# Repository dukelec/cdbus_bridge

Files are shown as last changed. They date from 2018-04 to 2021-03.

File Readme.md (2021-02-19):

## CDBUS Bridge

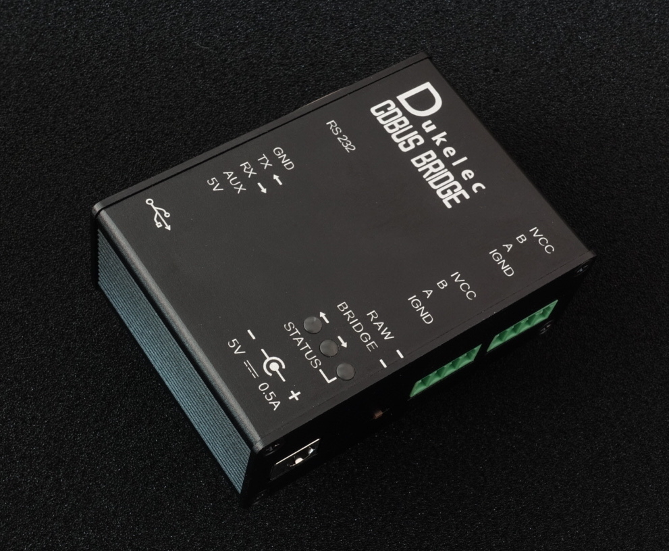
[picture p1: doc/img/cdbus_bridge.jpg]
cdbus_bridge

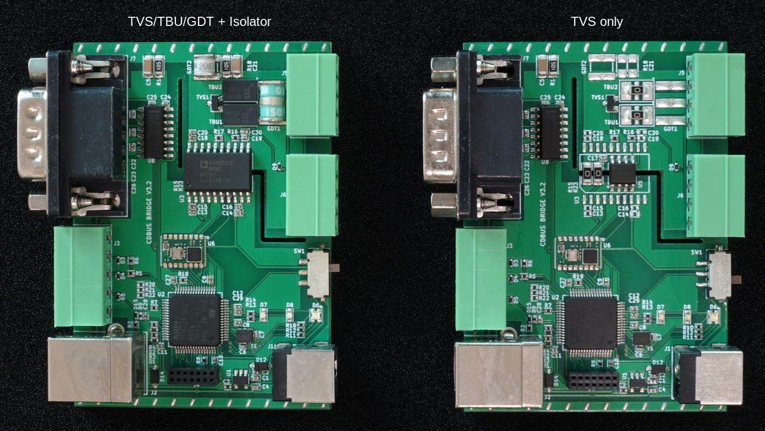
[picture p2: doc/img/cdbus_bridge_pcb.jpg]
cdbus_bridge_pcb


CDBUS Bridge has two types of communication ports, which are 3 serial ports and 2 RS485 ports:
 - Only one of the three serial ports will be in use at the same time. Inserting USB will switch over to the configuration-free USB serial port (the communication rate will not be affected by the selected baud rate);
 - The two RS485 ports are internally connected for easy wiring (or pull up, pull down, and termination resistors).

CDBUS Bridge has two modes (requires different firmware to be programmed, default is Bridge mode):

### Bridge Mode (Serial to RS485)

Switch Definition Changed: Forcing 115200 baud rate if the switch is in RAW when powering up.

bridge_mode

### Raw Mode (Serial passthrough)

raw_mode

## GUI Configuration

CDBUS GUI Tool: https://github.com/dukelec/cdbus_gui

When configuring the Bridge as the target, do not select the CDBUS Bridge selection box, set the local MAC to 0xaa and the target address to 80:00:55.

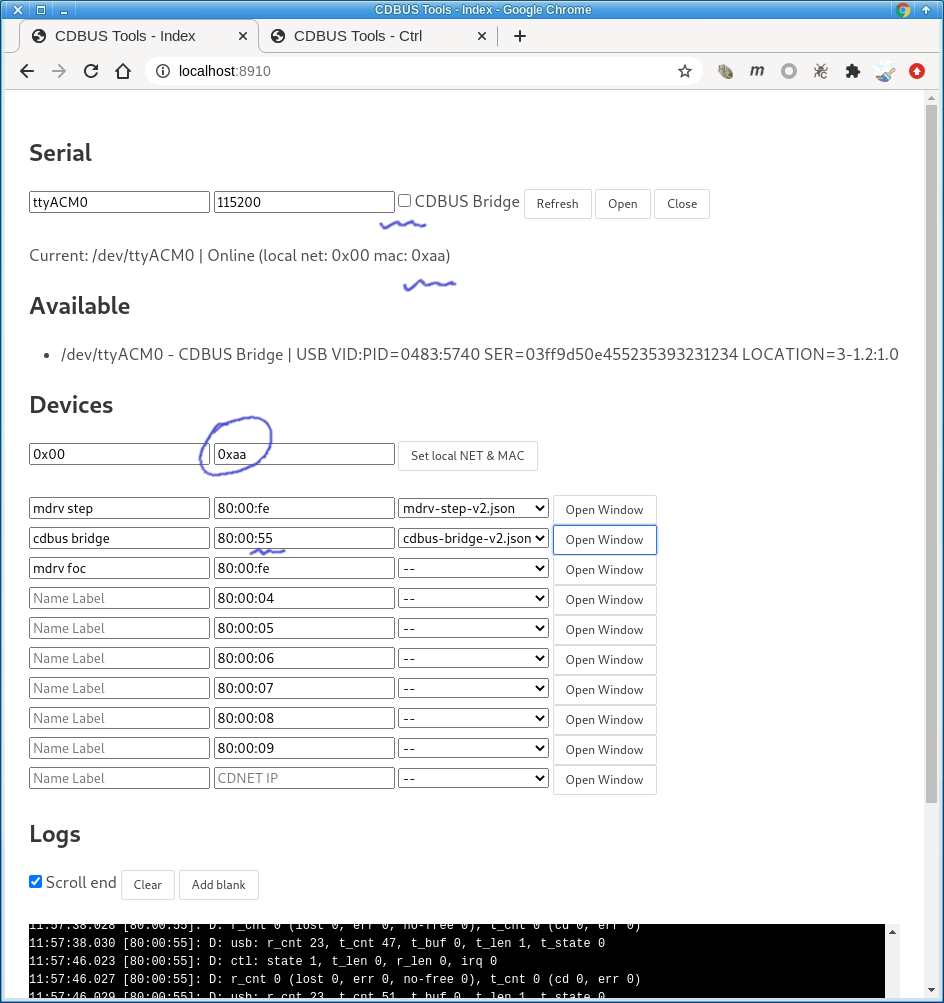
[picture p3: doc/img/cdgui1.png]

<br><br>

After modifying the configuration, write 1 to save_conf to save the configuration to flash.

If you need to restore the default configuration, change magic_code to another value and save it to flash. Then reapply power.

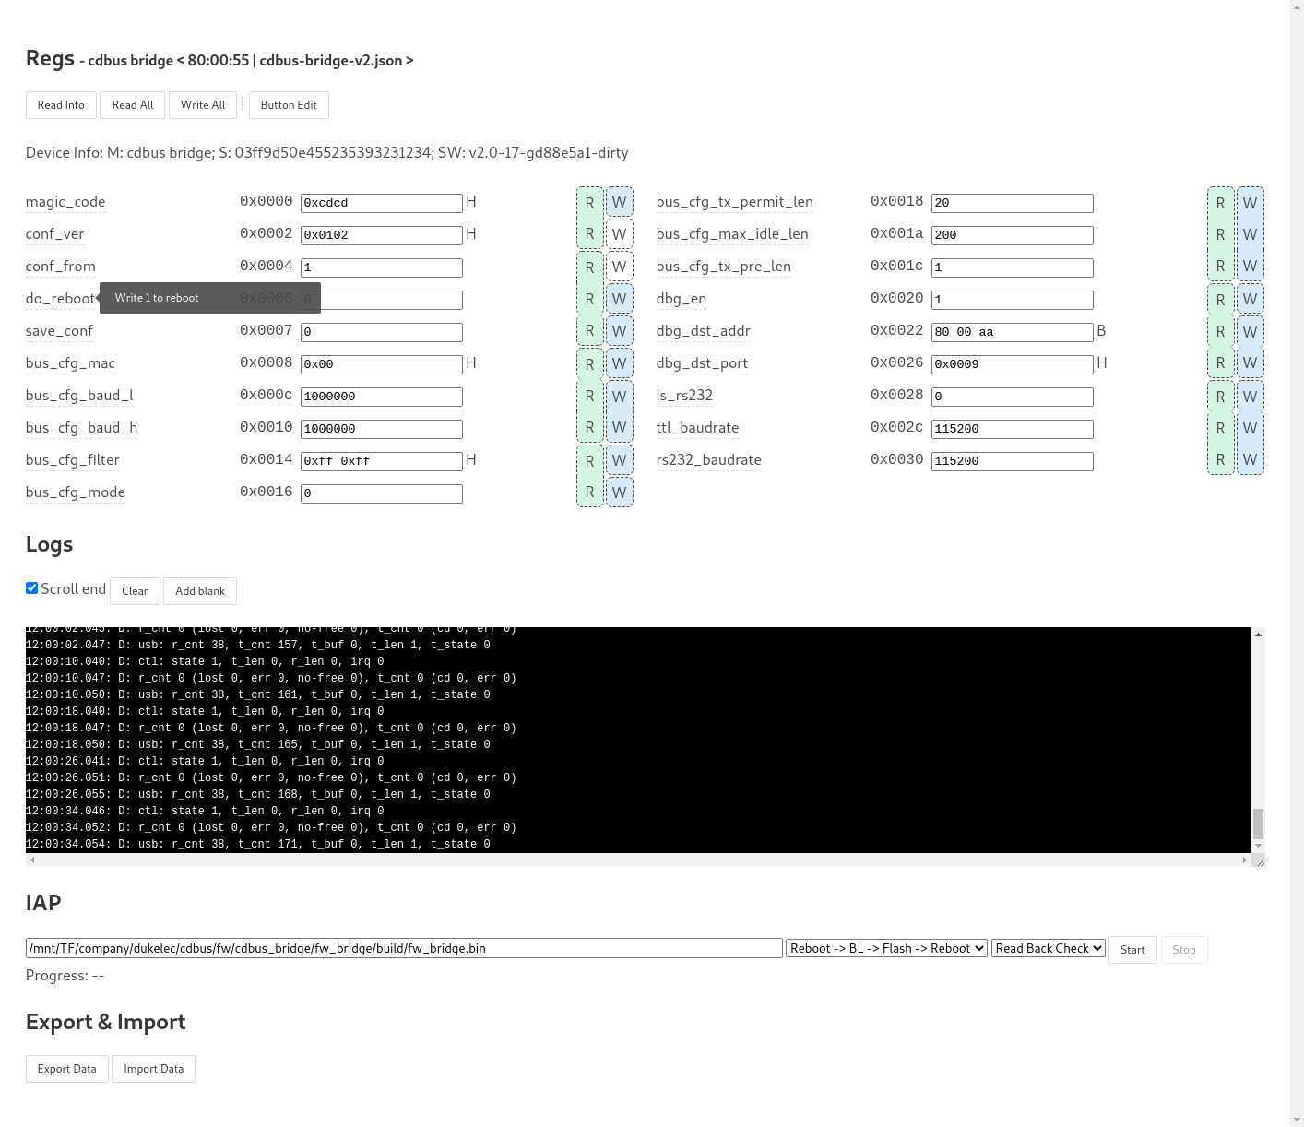
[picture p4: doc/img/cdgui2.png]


## Download Source Code

```
git clone --recurse-submodules https://github.com/dukelec/cdbus_bridge.git
```

## Test

### Prepare
 - Linux: pip3 install pythoncrc pyserial
 - Mac: pip3 install readline pythoncrc pyserial
 - Windows: pip3 install pyreadline pythoncrc pyserial

Please refer scripts' `--help` message and the `Readme.md` under `sw/` folder, e.g.:

```
cd sw/cdbus_tools/
./cdbus_terminal.py --help
```

Note: The default is 3 seconds for bootloader mode on power-on. The status light will flash when it jumps to the main program. Please use the relevant script tool (except IAP) after this.

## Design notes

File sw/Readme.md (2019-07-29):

### Read config from device
```
cdbus_tools/cdbus_iap.py --direct --addr=0x0801f800 --size=36 --out-file conf.bin
```

### Convert to cfg
```
./config_conv.py --to-cfg --bin conf.bin --cfg conf.cfg
```

#### Or creat cfg by default config
```
./config_conv.py --to-cfg --cfg conf.cfg
```

### Convert cfg back to bin
```
./config_conv.py --to-bin --cfg conf.cfg --bin conf.bin
```

### Write back to device
```
cdbus_tools/cdbus_iap.py --direct --addr=0x0801f800 --in-file conf.bin
```

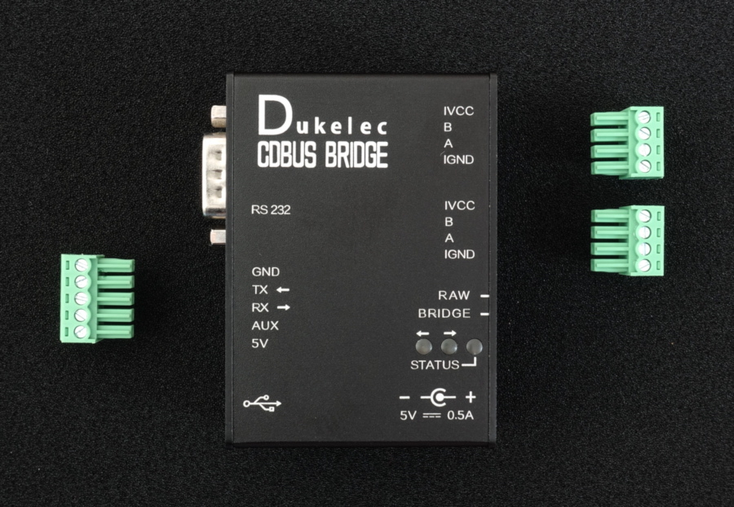
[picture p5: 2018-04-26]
doc/img/cdbus_bridge_top.jpg

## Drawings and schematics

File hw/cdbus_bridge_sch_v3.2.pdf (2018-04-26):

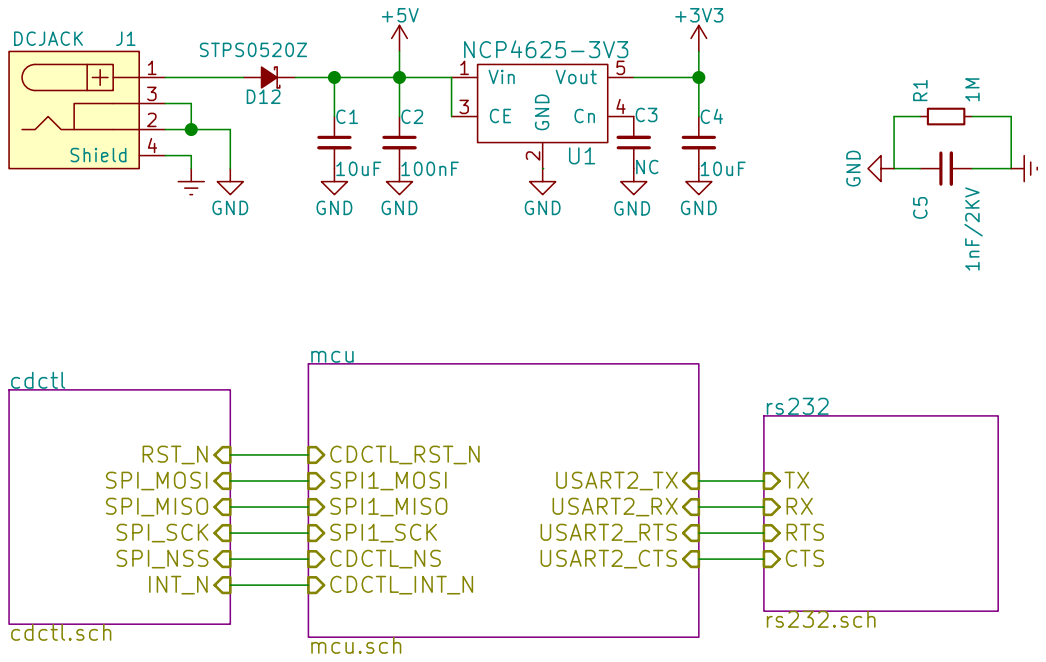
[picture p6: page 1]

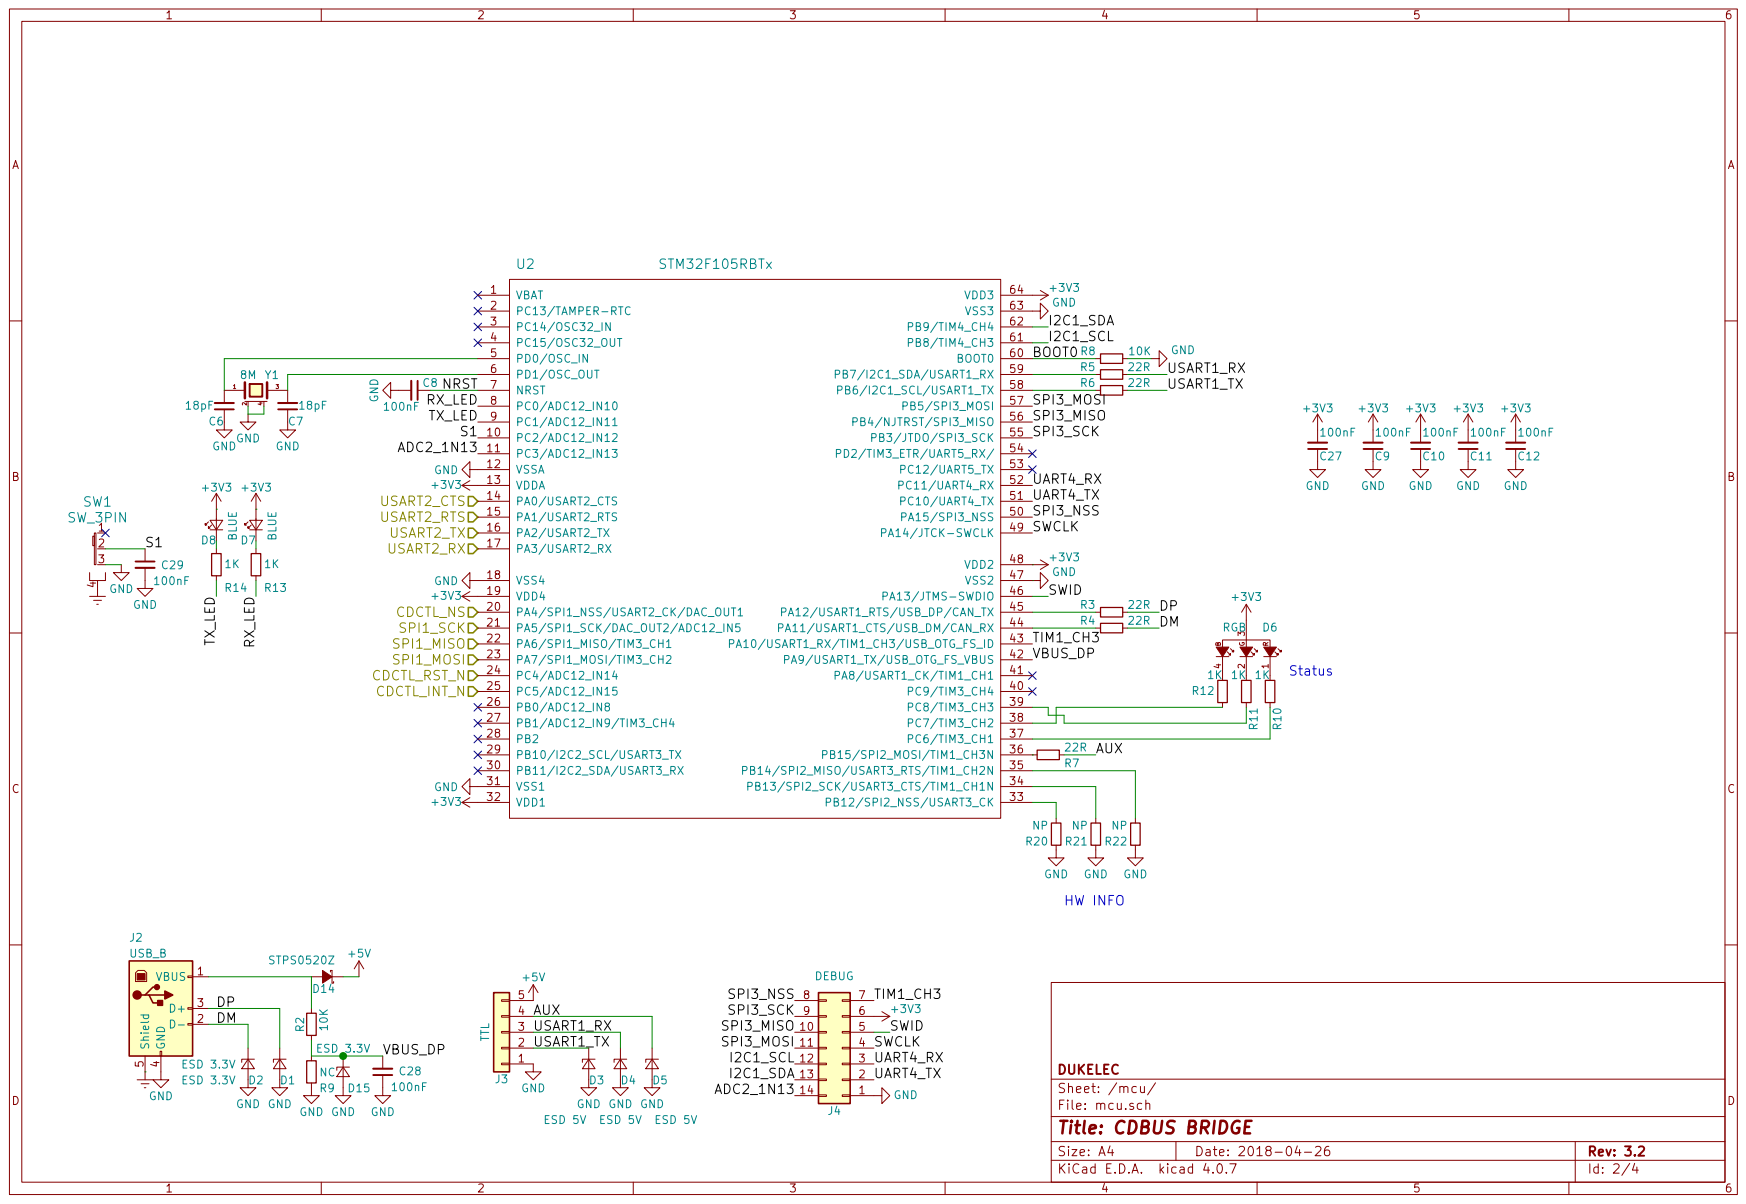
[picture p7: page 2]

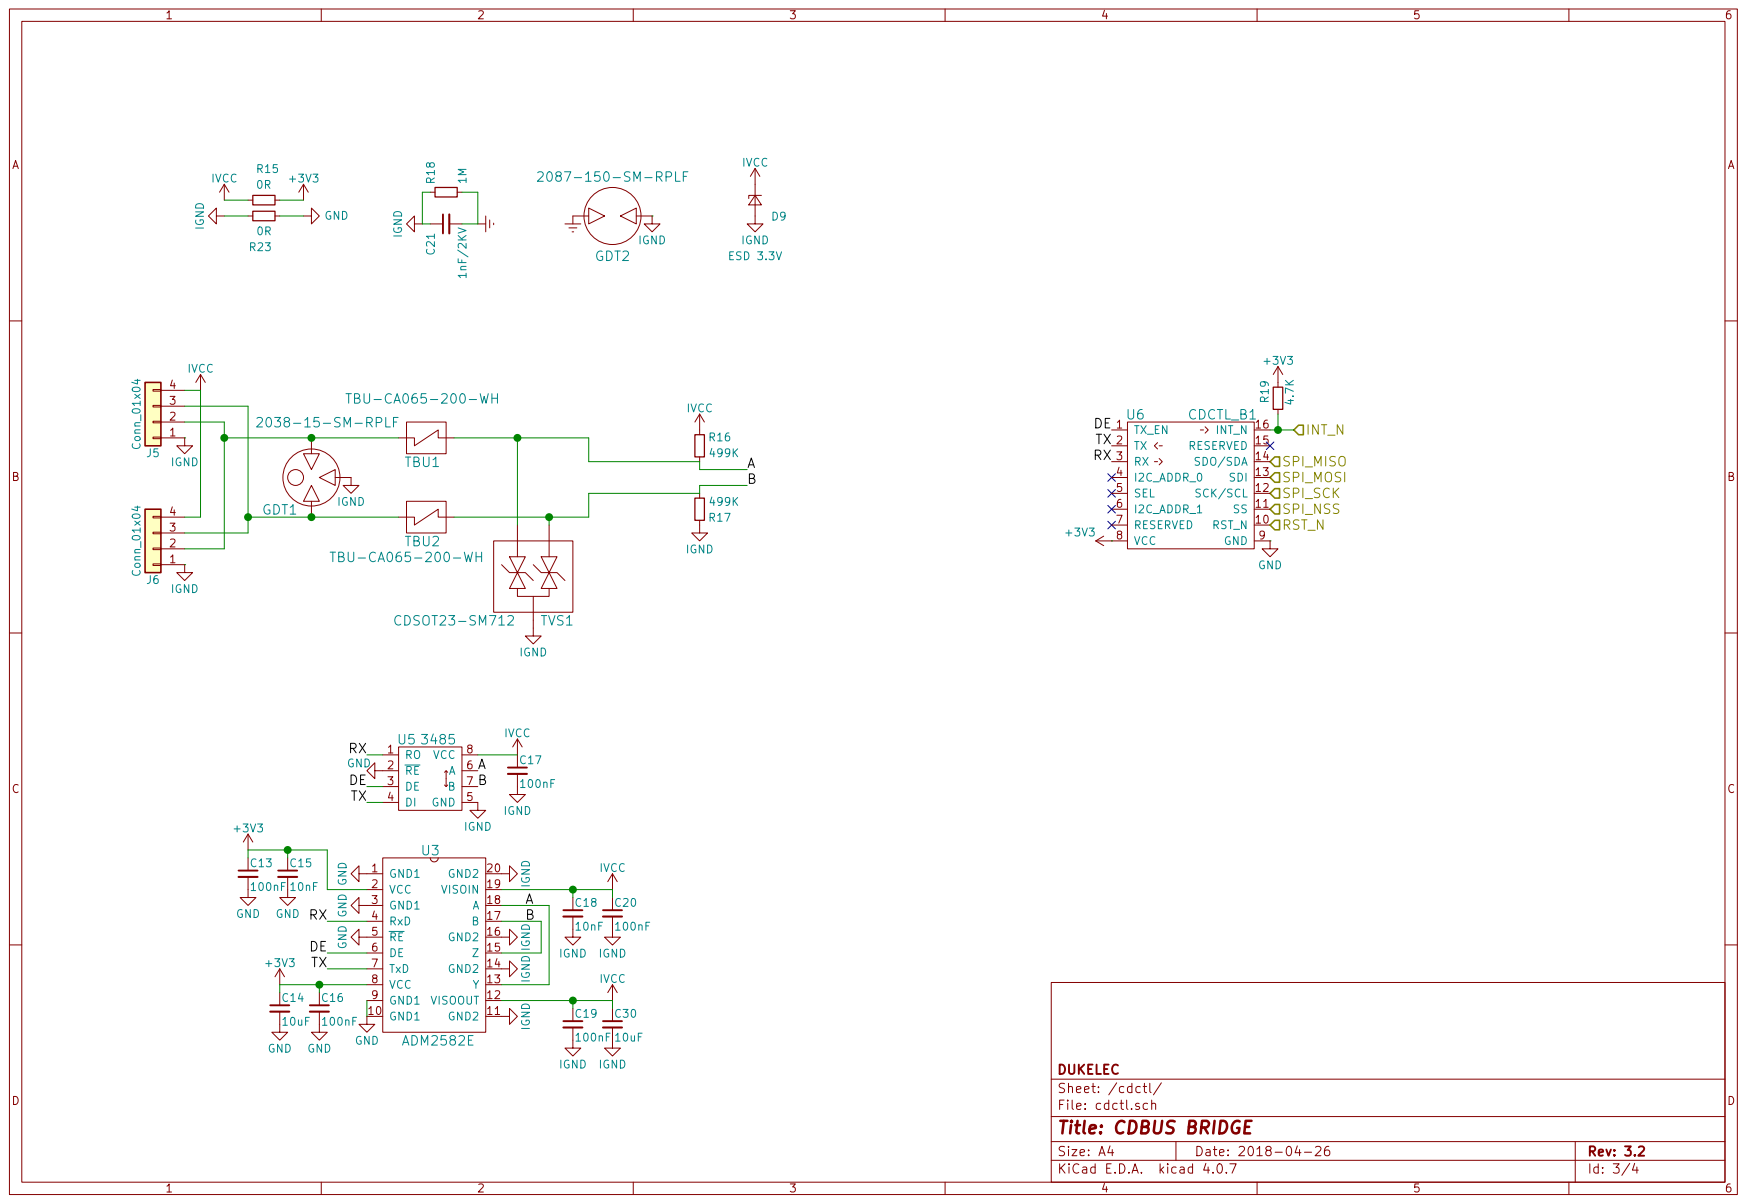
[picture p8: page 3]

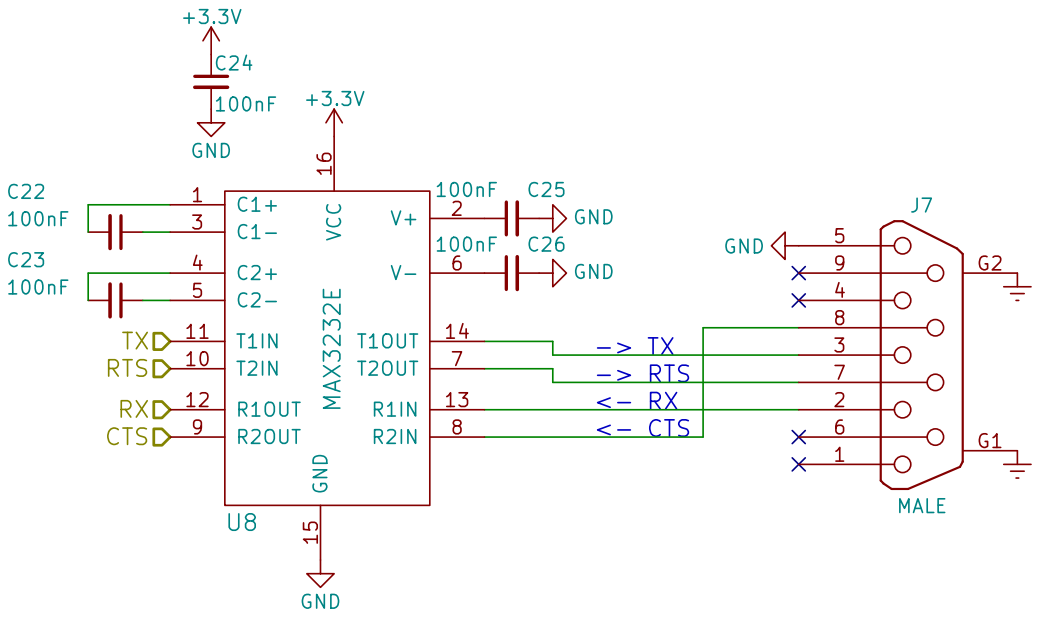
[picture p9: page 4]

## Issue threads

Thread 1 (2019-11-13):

请教，该项目里的 list 是线程安全的吗？

NikolaDi, 2019-11-13:
我想在linux 多线程环境中使用，是不是还要自己添加互斥锁？

NikolaDi, 2019-11-13:
是不是只要在 list_head_t 里加一个 pthread_mutex_t 就行了吧

dukelec, 2019-11-13:
我的這個版本不是線程安全的。
可以你那樣改，也可以考慮把鎖加在上一層用結構體中。
另外，linux kernel 中的 list 大多都是免鎖，你也可以瞭解一下。

NikolaDi, 2019-11-14:
thanks

Closed 2019-11-14.

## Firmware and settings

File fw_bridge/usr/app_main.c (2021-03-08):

/*
 * Software License Agreement (MIT License)
 *
 * Copyright (c) 2017, DUKELEC, Inc.
 * All rights reserved.
 *
 * Author: Duke Fong <duke@dukelec.com>
 */

#include "app_main.h"

extern ADC_HandleTypeDef hadc1;
extern UART_HandleTypeDef huart1;
extern UART_HandleTypeDef huart2;
extern UART_HandleTypeDef huart4;
extern SPI_HandleTypeDef hspi1;
extern USBD_HandleTypeDef hUsbDeviceFS;

static  gpio_t led_r = { .group = LED_R_GPIO_Port, .num = LED_R_Pin };
static  gpio_t led_g = { .group = LED_G_GPIO_Port, .num = LED_G_Pin };
static  gpio_t led_b = { .group = LED_B_GPIO_Port, .num = LED_B_Pin };
static  gpio_t led_tx = { .group = LED_TX_GPIO_Port, .num = LED_TX_Pin };
static  gpio_t led_rx = { .group = LED_RX_GPIO_Port, .num = LED_RX_Pin };
static  gpio_t sw = { .group = SW_MODE_GPIO_Port, .num = SW_MODE_Pin };

uart_t debug_uart = { .huart = &huart4 };
static uart_t ttl_uart = { .huart = &huart1 };
static uart_t rs232_uart = { .huart = &huart2 };
uart_t *hw_uart = NULL;

static gpio_t r_rst_n = { .group = CDCTL_RST_N_GPIO_Port, .num = CDCTL_RST_N_Pin };
static gpio_t r_int_n = { .group = CDCTL_INT_N_GPIO_Port, .num = CDCTL_INT_N_Pin };
static gpio_t r_ns = { .group = CDCTL_NS_GPIO_Port, .num = CDCTL_NS_Pin };
static spi_t r_spi = { .hspi = &hspi1, .ns_pin = &r_ns };

#define CDC_RX_MAX 6
#define CDC_TX_MAX 6
static cdc_buf_t cdc_rx_alloc[CDC_RX_MAX];
static cdc_buf_t cdc_tx_alloc[CDC_TX_MAX];
list_head_t cdc_rx_free_head = {0};
list_head_t cdc_tx_free_head = {0};
list_head_t cdc_rx_head = {0};
list_head_t cdc_tx_head = {0};
cdc_buf_t *cdc_rx_buf = NULL;
cdc_buf_t *cdc_tx_buf = NULL;

static cd_frame_t frame_alloc[FRAME_MAX];
list_head_t frame_free_head = {0};

static cdn_pkt_t packet_alloc[PACKET_MAX];

static cdctl_dev_t r_dev = {0};    // 485
cduart_dev_t d_dev = {0};   // uart / usb
cdn_ns_t dft_ns = {0};      // CDNET

int usb_rx_cnt = 0;
int usb_tx_cnt = 0;
static bool cdc_need_flush = false;

uint8_t circ_buf[CIRC_BUF_SZ];
uint32_t rd_pos = 0;

static int test_err = 0;
static int last_err = 0;
static uint32_t local_cnt = 0;
static uint32_t remote_cnt = 0;
static uint32_t cmd_in_cnt = 0;


static void device_init(void)
{
    int i;
    cdn_init_ns(&dft_ns);

    for (i = 0; i < CDC_RX_MAX; i++)
        list_put(&cdc_rx_free_head, &cdc_rx_alloc[i].node);
    for (i = 0; i < CDC_TX_MAX; i++)
        list_put(&cdc_tx_free_head, &cdc_tx_alloc[i].node);
    for (i = 0; i < FRAME_MAX; i++)
        list_put(&frame_free_head, &frame_alloc[i].node);
    for (i = 0; i < PACKET_MAX; i++)
        list_put(&dft_ns.free_pkts, &packet_alloc[i].node);

    cdc_rx_buf = list_get_entry(&cdc_rx_free_head, cdc_buf_t);

    if (gpio_get_value(&sw)) {
        csa.bus_cfg.baud_l = 115200;
        csa.bus_cfg.baud_h = 115200;
    }
    cdctl_dev_init(&r_dev, &frame_free_head, &csa.bus_cfg, &r_spi, &r_rst_n, &r_int_n);

    cduart_dev_init(&d_dev, &frame_free_head);
    d_dev.remote_filter[0] = 0xaa;
    d_dev.remote_filter_len = 1;
    d_dev.local_filter[0] = 0x55;
    d_dev.local_filter[1] = 0x56;
    d_dev.local_filter_len = 2;
    
    //                    uart / usb
    cdn_add_intf(&dft_ns, &d_dev.cd_dev, 0, 0x55);

    if (!csa.is_rs232) {
        hw_uart = &ttl_uart;
    } else {
        hw_uart = &rs232_uart;
    }
}

void set_led_state(led_state_t state)
{
    static bool is_err = false;
    if (is_err)
        return;

    switch (state) {
    case LED_POWERON:
        gpio_set_value(&led_r, 1);
        gpio_set_value(&led_g, 1);
        gpio_set_value(&led_b, 0);
        break;
    case LED_WARN:
        gpio_set_value(&led_r, 0);
        gpio_set_value(&led_g, 0);
        gpio_set_value(&led_b, 1);
        break;
    default:
    case LED_ERROR:
        is_err = true;
        gpio_set_value(&led_r, 0);
        gpio_set_value(&led_g, 1);
        gpio_set_value(&led_b, 1);
        break;
    }
}

static void data_led_task(void)
{
    static uint32_t tx_t_last = 0;
    static uint32_t rx_t_last = 0;
    static uint32_t tx_cnt_last = 0;
    static uint32_t rx_cnt_last = 0;

    if (rx_cnt_last != cmd_in_cnt) {
        rx_cnt_last = cmd_in_cnt;
        rx_t_last = get_systick();
        gpio_set_value(&led_rx, 0);
    }
    if (tx_cnt_last != local_cnt) {
        tx_cnt_last = local_cnt;
        tx_t_last = get_systick();
        gpio_set_value(&led_tx, 0);
    }
    /*
    if (rx_cnt_last != r_dev.rx_cnt) {
        rx_cnt_last = r_dev.rx_cnt;
        rx_t_last = get_systick();
        gpio_set_value(&led_rx, 0);
    }
    if (tx_cnt_last != r_dev.tx_cnt) {
        tx_cnt_last = r_dev.tx_cnt;
        tx_t_last = get_systick();
        gpio_set_value(&led_tx, 0);
    }
    */

    if (gpio_get_value(&led_rx) == 0 && get_systick() - rx_t_last > 10)
        gpio_set_value(&led_rx, 1);
    if (gpio_get_value(&led_tx) == 0 && get_systick() - tx_t_last > 10)
        gpio_set_value(&led_tx, 1);
}


extern uint32_t end; // end of bss
#define STACK_CHECK_SKIP 0x200
#define STACK_CHECK_SIZE (64 + STACK_CHECK_SKIP)

static void stack_check_init(void)
{
    int i;
    printf("stack_check_init: skip: %p ~ %p, to %p\n",
            &end, &end + STACK_CHECK_SKIP, &end + STACK_CHECK_SIZE);
    for (i = STACK_CHECK_SKIP; i < STACK_CHECK_SIZE; i+=4)
        *(uint32_t *)(&end + i) = 0xababcdcd;
}

static void stack_check(void)
{
    int i;
    for (i = STACK_CHECK_SKIP; i < STACK_CHECK_SIZE; i+=4) {
        if (*(uint32_t *)(&end + i) != 0xababcdcd) {
            printf("stack overflow %p (skip: %p ~ %p): %08lx\n",
                    &end + i, &end, &end + STACK_CHECK_SKIP, *(uint32_t *)(&end + i));
            while (true);
        }
    }
}


static void dump_hw_status(void)
{
    static int t_l = 0;
    if (get_systick() - t_l > 8000) {
        //USBD_CDC_HandleTypeDef *hcdc = (USBD_CDC_HandleTypeDef*)hUsbDeviceFS.pClassData;
        t_l = get_systick();

        d_debug("ctl: state %d, t_len %d, r_len %d, irq %d\n",
                r_dev.state, r_dev.tx_head.len, r_dev.rx_head.len,
                !gpio_get_value(r_dev.int_n));
        d_debug("  r_cnt %d (lost %d, err %d, no-free %d), t_cnt %d (cd %d, err %d)\n",
                r_dev.rx_cnt, r_dev.rx_lost_cnt, r_dev.rx_error_cnt,
                r_dev.rx_no_free_node_cnt,
                r_dev.tx_cnt, r_dev.tx_cd_cnt, r_dev.tx_error_cnt);
        //d_debug("usb: r_cnt %d, t_cnt %d, t_buf %p, t_len %d, t_state %x\n",
        //        usb_rx_cnt, usb_tx_cnt, cdc_tx_buf, cdc_tx_head.len, hcdc->TxState);
        d_info("TTT: local_cnt %d, remote_cnt %d\n", local_cnt, remote_cnt);
        if (test_err || last_err)
            d_error("test: err_cnt %d, last: %d !!!!!!!!\n", test_err, last_err);
    }
}


void cdbus_test(void)
{
    static uint32_t size = 0;
    uint8_t target_mac;

    cd_dev_t *cd_dev = &r_dev.cd_dev;
    target_mac = ~csa.bus_cfg.mac; // avoid addr 0, or specify an address

    if (gpio_get_value(&sw)) {
        cd_frame_t *frame = cd_dev->get_free_frame(cd_dev);
        if (frame) {
            frame->dat[0] = csa.bus_cfg.mac;
            frame->dat[1] = target_mac;
            frame->dat[2] = size; // frame size
            *(uint32_t *)&frame->dat[4] = local_cnt++;
            cd_dev->put_tx_frame(cd_dev, frame);

            if (++size > 253)
                size = 0;
        }
    }
}


void app_main(void)
{
    printf("\nstart app_main (bridge)...\n");
    stack_check_init();
    debug_init(&dft_ns, &csa.dbg_dst, &csa.dbg_en);
    load_conf();
    device_init();
    common_service_init();
    printf("conf: %s\n", csa.conf_from ? "load from flash" : "use default");
    d_info("conf: %s\n", csa.conf_from ? "load from flash" : "use default");
    set_led_state(LED_POWERON);
    app_bridge_init();
    HAL_UART_Receive_DMA(hw_uart->huart, circ_buf, CIRC_BUF_SZ);
    csa_list_show();

    while (true) {
        USBD_CDC_HandleTypeDef *hcdc = (USBD_CDC_HandleTypeDef*)hUsbDeviceFS.pClassData;

        if (!csa.usb_online && hUsbDeviceFS.dev_state == USBD_STATE_CONFIGURED) {
            printf("usb connected\n");
            csa.usb_online = true;
            HAL_UART_DMAStop(hw_uart->huart);
        }

        if (cdc_tx_buf) {
            if (csa.usb_online) {
                if (hcdc->TxState == 0) {
                    list_put(&cdc_tx_free_head, &cdc_tx_buf->node);
                    cdc_tx_buf = NULL;
                }
            } else { // hw_uart
                if (hw_uart->huart->TxXferCount == 0) {
                    hw_uart->huart->gState = HAL_UART_STATE_READY;
                    list_put(&cdc_tx_free_head, &cdc_tx_buf->node);
                    cdc_tx_buf = NULL;
                    //d_verbose("hw_uart dma done.\n");
                }
            }
        }
        if (cdc_tx_head.first) {
            if (!cdc_tx_buf && hcdc->TxState == 0) {
                cdc_buf_t *bf = list_entry(cdc_tx_head.first, cdc_buf_t);
                if (bf->len != 0) {
                    if (csa.usb_online) {
                        local_irq_disable();
                        CDC_Transmit_FS(bf->dat, bf->len);
                        local_irq_enable();
                        cdc_need_flush = true;
                    } else { // hw_uart
                        //d_verbose("hw_uart dma tx...\n");
                        HAL_UART_Transmit_DMA(hw_uart->huart, bf->dat, bf->len);
                    }
                    list_get(&cdc_tx_head);
                    cdc_tx_buf = bf;

                } else if (cdc_need_flush) {
                    local_irq_disable();
                    CDC_Transmit_FS(NULL, 0);
                    local_irq_enable();
                    cdc_need_flush = false;
                }
            }
        }

        data_led_task();
        stack_check();
        cdbus_test();
        dump_hw_status();
        cdn_routine(&dft_ns); // handle cdnet
        common_service_routine();
        app_bridge();
        debug_flush(false);
    }
}


void HAL_GPIO_EXTI_Callback(uint16_t GPIO_Pin)
{
    if (GPIO_Pin == r_int_n.num) {
        cdctl_int_isr(&r_dev);
    }
}

void HAL_SPI_TxRxCpltCallback(SPI_HandleTypeDef *hspi)
{
    cdctl_spi_isr(&r_dev);
}
void HAL_SPI_RxCpltCallback(SPI_HandleTypeDef *hspi)
{
    cdctl_spi_isr(&r_dev);
}
void HAL_SPI_TxCpltCallback(SPI_HandleTypeDef *hspi)
{
    cdctl_spi_isr(&r_dev);
}
void HAL_SPI_ErrorCallback(SPI_HandleTypeDef *hspi)
{
    d_error("spi error...\n");
}

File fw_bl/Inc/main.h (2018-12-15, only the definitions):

#define LED_RX_Pin GPIO_PIN_0
#define LED_RX_GPIO_Port GPIOC
#define LED_TX_Pin GPIO_PIN_1
#define LED_TX_GPIO_Port GPIOC
#define SW_MODE_Pin GPIO_PIN_2
#define SW_MODE_GPIO_Port GPIOC
#define CDCTL_NS_Pin GPIO_PIN_4
#define CDCTL_NS_GPIO_Port GPIOA
#define CDCTL_RST_N_Pin GPIO_PIN_4
#define CDCTL_RST_N_GPIO_Port GPIOC
#define CDCTL_INT_N_Pin GPIO_PIN_5
#define CDCTL_INT_N_GPIO_Port GPIOC
#define CDCTL_INT_N_EXTI_IRQn EXTI9_5_IRQn
#define LED_R_Pin GPIO_PIN_6
#define LED_R_GPIO_Port GPIOC
#define LED_B_Pin GPIO_PIN_7
#define LED_B_GPIO_Port GPIOC
#define LED_G_Pin GPIO_PIN_8
#define LED_G_GPIO_Port GPIOC

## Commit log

2018-01-04 init from stm32cube
2018-01-06 stm32cube: enable sw debug port; enable uart interrupt
2018-01-14 update cdnet: dev/cdctl_bx: fix zero byte r/w for 256 bytes frame ...
    [cdbus_bridge.ioc, main.h]
2018-01-14 stm32cube: add LEDs
2018-01-15 stm32cube: select usb cdc
2018-01-21 stm32cube: select DMA for SPI and UART
2018-01-23 stm32cube: uart circular dma, spi soft nss, int_n interrupt
2018-01-23 hal dma: fix spi finish irq lost; also disable the half complete irq, improve performance.
2018-02-16 update app_main to use usb and uart ring buffer
2018-02-18 passing basic test for pass-through app through device cdc and hw_uart
2018-02-22 stm32cube: update cube version
2018-02-24 update: fix list_for_each for remove node during the loop, and list mess
    [app_main.c]
2018-03-21 stm32cube: change to stm32f105rbtx
2018-03-22 stm32cube: spi dma interrupt sub priority: rx should set lower than tx, to avoid tx dma channel still set as HAL_BUSY during next spi operation which start from the rx callback. A better way to solve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
    stm32cube: set interrupt priority of system higher than users,
    especially for the systick.
    [cdbus_bridge.ioc]
2018-04-26 rename folder; add sch & pcb
    [cdbus_bridge-B.Cu.gbr, cdbus_bridge-B.Mask.gbr, cdbus_bridge-B.Paste.gbr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]
2018-05-22 stm32cube: change pins for rgb led, according to hardware version v3.2
2018-05-23 add pcb photo
2018-05-27 stm32cube: enable adc for random value
2018-05-27 fw: init uart baudrate from app_conf
2018-12-15 stm32cube upgrade; correct usart rx dma mode to circular
    [cdbus_bridge.ioc, main.h]
2018-12-23 fix sock typo in common_services.c; update sw/cdbus_tools
    [common_services.c, config.c]
2020-10-22 fix error after save config
    [app_bridge.c, app_main.c, bl.c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]
2021-02-04 update cdnet; force cdc flush tx, avoid package with 64 bytes size held
    [app_bridge.c, app_main.c, common_services.c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]
2021-02-10 force to 115200 by switch

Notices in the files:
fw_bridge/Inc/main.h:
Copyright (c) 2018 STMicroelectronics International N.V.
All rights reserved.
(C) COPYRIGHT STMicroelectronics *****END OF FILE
